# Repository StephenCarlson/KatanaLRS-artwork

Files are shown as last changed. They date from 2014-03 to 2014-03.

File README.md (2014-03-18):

KatanaLRS-artwork
=================

Hardware Files: Schematics and Layouts, Gerbers, PDFs

License
-------

This work is licensed under the Creative Commons Attribution-ShareAlike 3.0 Unported License. To view a copy of this license, visit <http://creativecommons.org/licenses/by-sa/3.0/> or send a letter to Creative Commons, 444 Castro Street, Suite 900, Mountain View, California, 94041, USA.

*Some portions of code may be subject to different licensing agreements.

THE SOFTWARE IS PROVIDED “AS IS”, WITHOUT WARRANTY OF ANY KIND, EXPRESS OR IMPLIED, INCLUDING BUT NOT LIMITED TO THE WARRANTIES OF MERCHANTABILITY, FITNESS FOR A PARTICULAR PURPOSE AND NONINFRINGEMENT. IN NO EVENT SHALL THE AUTHORS OR COPYRIGHT HOLDERS BE LIABLE FOR ANY CLAIM, DAMAGES OR OTHER LIABILITY, WHETHER IN AN ACTION OF CONTRACT, TORT OR OTHERWISE, ARISING FROM, OUT OF OR IN CONNECTION WITH THE SOFTWARE OR THE USE OR OTHER DEALINGS IN THE SOFTWARE.

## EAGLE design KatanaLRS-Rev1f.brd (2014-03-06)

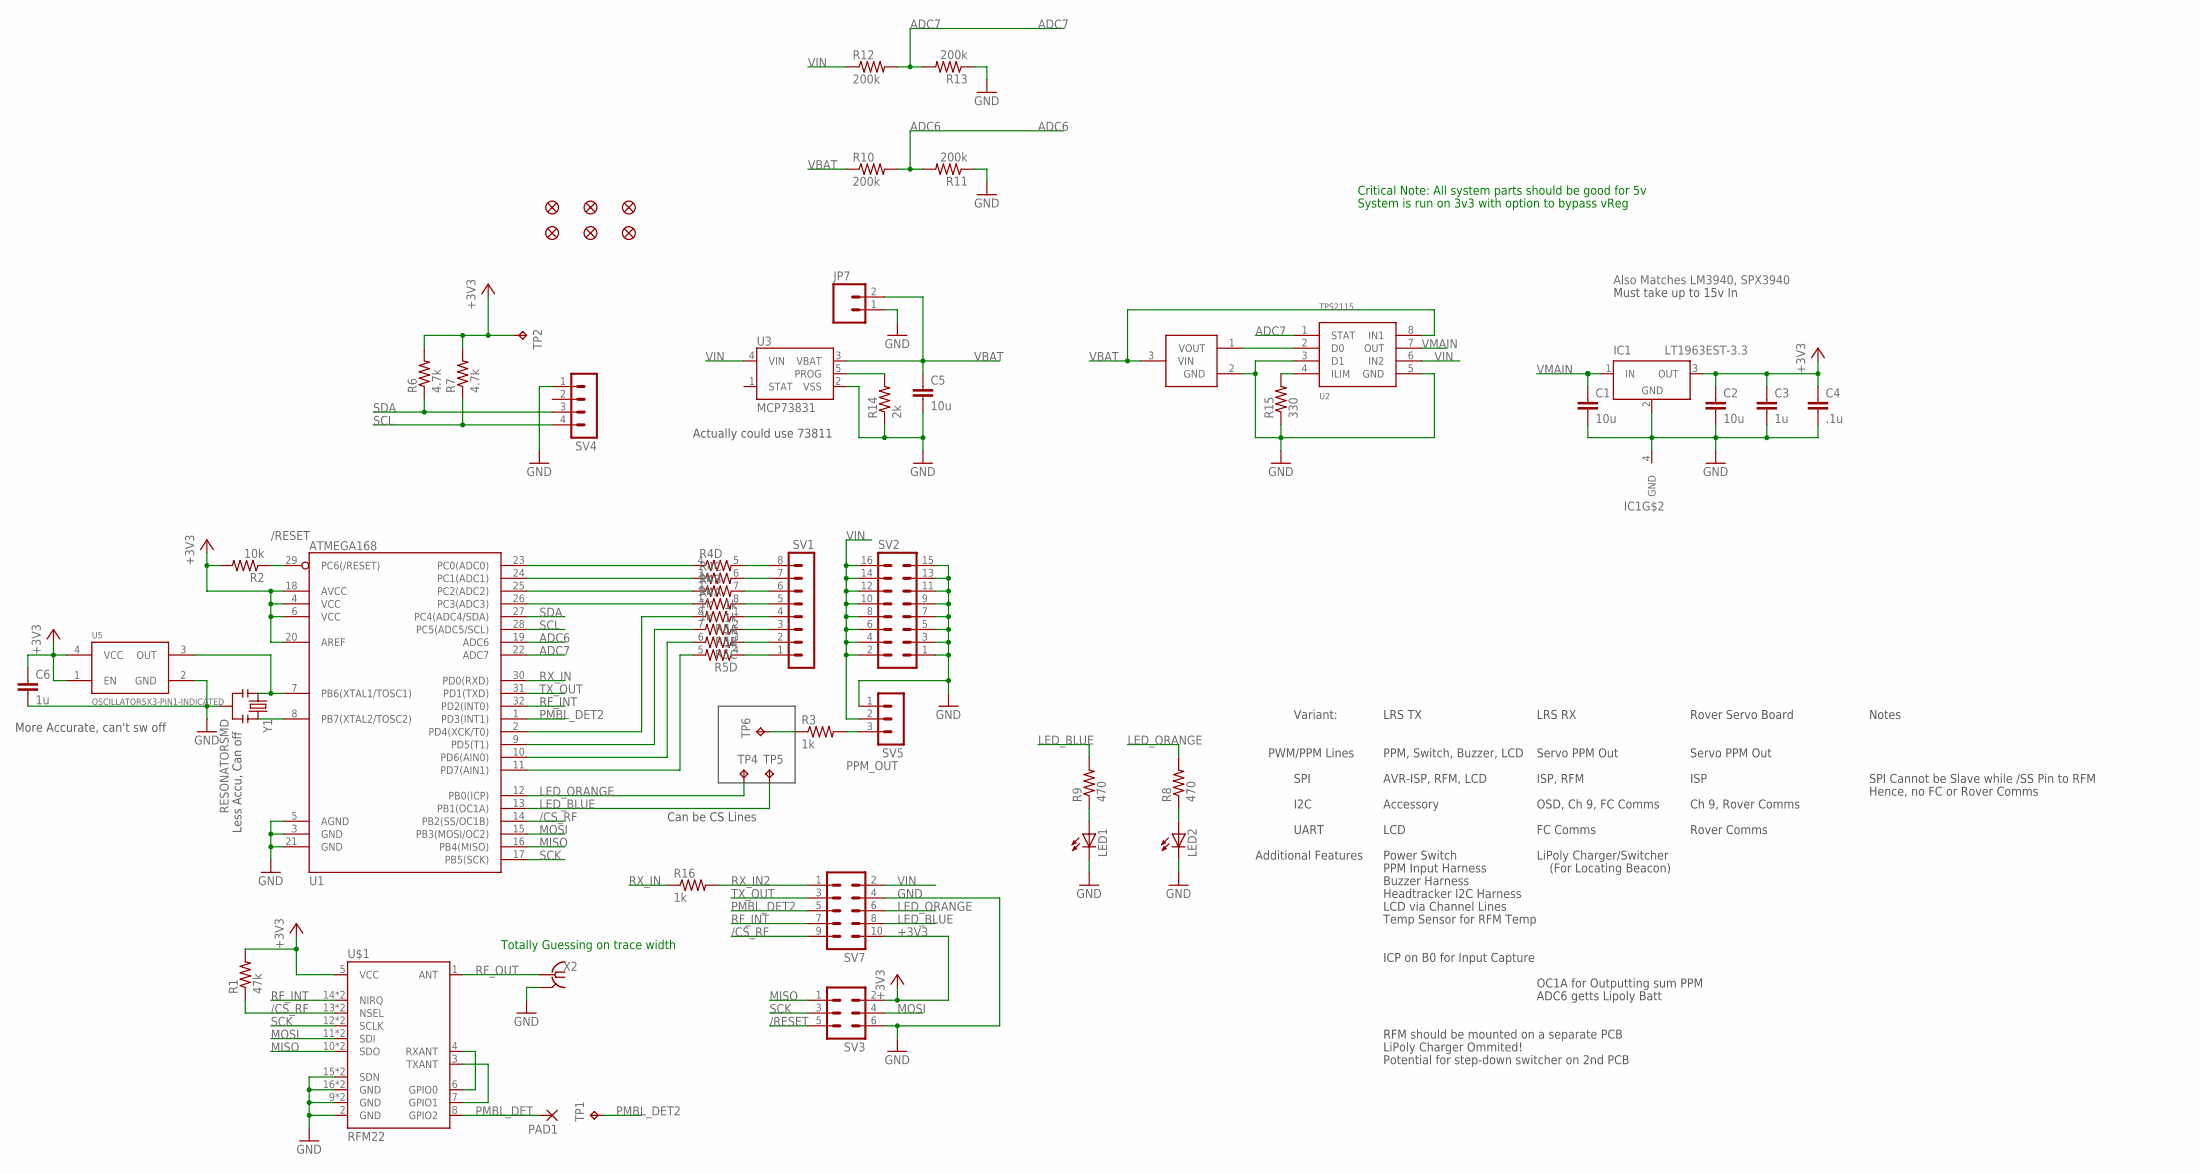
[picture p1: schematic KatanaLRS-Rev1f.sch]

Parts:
C1, C2, C5: 10u; 1206
C3: 1u; 0603-CAP
C4: .1u; 0603-CAP
C6: 1u; 0805
IC1: LT1963EST-3.3; SOT223
JP1, JP2, JP3, JP4, JP6, JP11: FIDUCIAL1X2; FIDUCIAL-1X2
JP7: M02JST-PTH-2; JST-2-PTH
LED1, LED2: LED1206; LED-1206
PAD1: SMD2; SMD1,27-2,54
R1: 47k; R0603
R2: 10k; R0603
R3, R16: 1k; R0603
R4, R5: 1k; 0603-ARV
R6, R7: 4.7k; R0603
R8, R9: 470; R0805
R10, R11, R12, R13: 200k; R0603
R14: 2k; R0603
R15: 330; R0603
SV1: MA08-1
SV2: MA08-2
SV3: MA03-2
SV4: MA04-1
SV5: MA03-1
SV7: MA05-2
TP1, TP2: TPTP15SQ; TP15SQ
TP4, TP5: TPTP07SQ; TP07SQ
TP6: TPTP10SQ; TP10SQ
U1: ATMEGA168; TQFP32-08
U2: TPS2115; TSSOP8
U3: MCP73831; SOT23-5
U5: OSCILLATOR5X3-PIN1-INDICATED; CRYSTAL-OSC-SMD-5X3
U$1: RFM22; RFM23B
U$4: TC54VC3002ECB713; SOT23-3
X2: Molex 073391-0060; BU-SMA-H
Y1: RESONATORSMD; RESONATOR-SMD

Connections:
+3V3: C2.1, C3.1, C4.1, C6.1, IC1.3 (OUT), R1.2, R2.2, R6.2, R7.2, SV3.2, SV7.10, TP2.TP, U1.4 (VCC), U1.6 (VCC), U1.18 (AVCC), U1.20 (AREF), U5.1 (EN), U5.4 (VCC), U$1.5 (VCC)
/CS_RF: R1.1, SV7.9, U1.14 (PB2(SS/OC1B)), U$1.13 (NSEL), U$1.13B (NSEL)
/RESET: R2.1, SV3.5, U1.29 (PC6(/RESET))
ADC6: R10.2, R11.2, U1.19 (ADC6)
ADC7: R12.2, R13.2, U1.22 (ADC7), U2.1 (STAT)
DP1: R5.7 (2), U1.9 (PD5(T1))
GND: C1.2, C2.2, C3.2, C4.2, C5.2, C6.2, IC1.2 (GND), IC1.4 (GND), JP7.1, LED1.C, LED2.C, R11.1, R13.1, R14.1, R15.1, SV2.1, SV2.3, SV2.5, SV2.7, SV2.9, SV2.11, SV2.13, SV2.15, SV3.6, SV4.1, SV5.1, SV7.4, U1.3 (GND), U1.5 (AGND), U1.21 (GND), U2.3 (D1), U2.5 (GND), U3.2 (VSS), U5.2 (GND), U$1.2 (GND), U$1.9 (GND), U$1.9B (GND), U$1.15 (SDN), U$1.15B (SDN), U$1.16 (GND), U$1.16B (GND), U$4.2 (GND), X2.2 (GND), X2.3 (GND), X2.4 (GND), X2.5 (GND), Y1.2
LED_BLUE: R9.2, SV7.8, TP5.TP, U1.13 (PB1(OC1A))
LED_ORANGE: R8.2, SV7.6, TP4.TP, U1.12 (PB0(ICP))
MISO: SV3.1, U1.16 (PB4(MISO)), U$1.10 (SDO), U$1.10B (SDO)
MOSI: SV3.4, U1.15 (PB3(MOSI/OC2)), U$1.11 (SDI), U$1.11B (SDI)
unnamed: R4.4 (1), U1.23 (PC0(ADC0))
unnamed: R4.3 (1), U1.24 (PC1(ADC1))
unnamed: U1.8 (PB7(XTAL2/TOSC2)), Y1.3
unnamed: U1.7 (PB6(XTAL1/TOSC1)), U5.3 (OUT), Y1.1
unnamed: R4.2 (1), U1.25 (PC2(ADC2))
unnamed: R15.2, U2.4 (ILIM)
unnamed: R4.1, U1.26 (PC3(ADC3))
unnamed: U$1.4 (RXANT), U$1.6 (GPIO0)
unnamed: LED1.A, R9.1
unnamed: R4.8 (2), SV1.5
unnamed: R4.7 (2), SV1.6
unnamed: R4.6 (2), SV1.7
unnamed: R4.5 (2), SV1.8
unnamed: U$1.3 (TXANT), U$1.7 (GPIO1)
unnamed: R5.4 (1), SV1.1
unnamed: R5.6 (2), U1.10 (PD6(AIN0))
unnamed: R5.3 (1), SV1.2
unnamed: R5.5 (2), U1.11 (PD7(AIN1))
unnamed: R5.8 (2), U1.2 (PD4(XCK/T0))
unnamed: U2.2 (D0), U$4.1 (VOUT)
unnamed: LED2.A, R8.1
unnamed: R3.1, TP6.TP
unnamed: R5.2 (1), SV1.3
unnamed: R5.1, SV1.4
unnamed: R14.2, U3.5 (PROG)
PMBL_DET: PAD1.1, U$1.8 (GPIO2)
PMBL_DET2: SV7.5, TP1.TP, U1.1 (PD3(INT1))
PPM_OUT: R3.2, SV5.3
RF_INT: SV7.7, U1.32 (PD2(INT0)), U$1.14 (NIRQ), U$1.14B (NIRQ)
RF_OUT: U$1.1 (ANT), X2.1
RX_IN: R16.1, U1.30 (PD0(RXD))
RX_IN2: R16.2, SV7.1
SCK: SV3.3, U1.17 (PB5(SCK)), U$1.12 (SCLK), U$1.12B (SCLK)
SCL: R7.1, SV4.4, U1.28 (PC5(ADC5/SCL))
SDA: R6.1, SV4.3, U1.27 (PC4(ADC4/SDA))
TX_OUT: SV7.3, U1.31 (PD1(TXD))
VBAT: C5.1, JP7.2, R10.1, U2.8 (IN1), U3.3 (VBAT), U$4.3 (VIN)
VIN: R12.1, SV2.2, SV2.4, SV2.6, SV2.8, SV2.10, SV2.12, SV2.14, SV2.16, SV5.2, SV7.2, U2.6 (IN2), U3.4 (VIN)
VMAIN: C1.1, IC1.1 (IN), U2.7 (OUT)

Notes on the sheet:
Variant:
PWM/PPM Lines
LRS TX
LRS RX
Rover Servo Board
PPM, Switch, Buzzer, LCD
Servo PPM Out
SPI
AVR-ISP, RFM, LCD
ISP, RFM
ISP
I2C
Accessory
OSD, Ch 9, FC Comms
Ch 9, Rover Comms
UART
LCD
FC Comms
Rover Comms
Additional Features
LiPoly Charger/Switcher
(For Locating Beacon)
Notes
SPI Cannot be Slave while /SS Pin to RFM
Hence, no FC or Rover Comms
Can be CS Lines
Power Switch
PPM Input Harness
Buzzer Harness
Headtracker I2C Harness
LCD via Channel Lines
Temp Sensor for RFM Temp
ICP on B0 for Input Capture
OC1A for Outputting sum PPM
Critical Note: All system parts should be good for 5v
System is run on 3v3 with option to bypass vReg
ADC6 getts Lipoly Batt
RFM should be mounted on a separate PCB
Totally Guessing on trace width
More Accurate, can't sw off

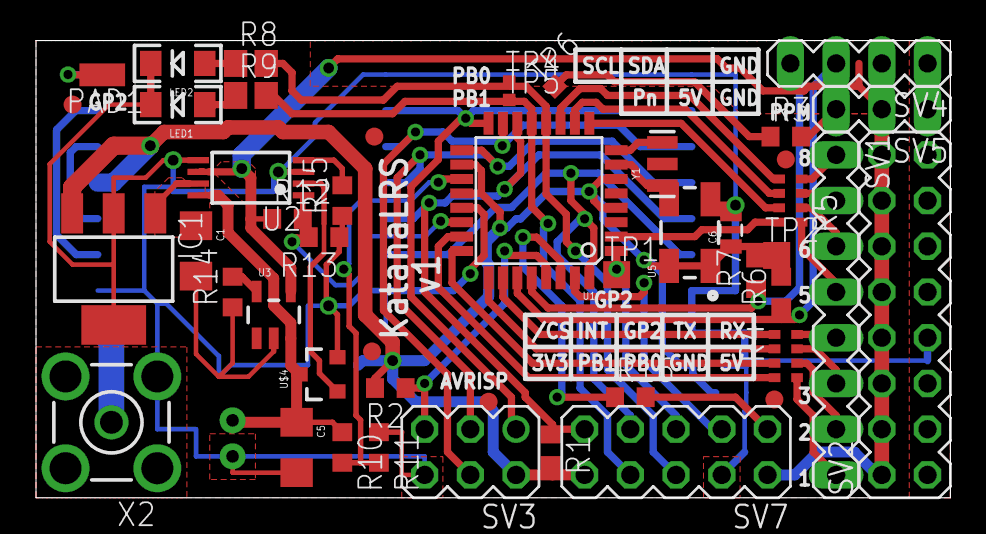
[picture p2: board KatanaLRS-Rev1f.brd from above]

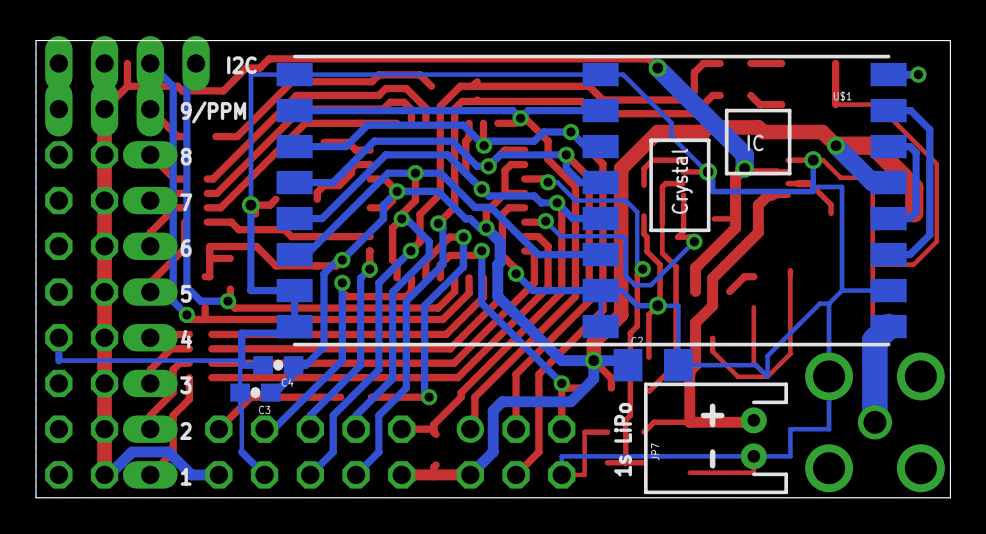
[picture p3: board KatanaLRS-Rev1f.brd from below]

Board: 2 copper layers, 50.8 x 25.4 mm, 52 parts (5 on the bottom side), 50 nets.

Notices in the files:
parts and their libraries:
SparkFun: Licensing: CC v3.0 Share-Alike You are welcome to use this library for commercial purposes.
